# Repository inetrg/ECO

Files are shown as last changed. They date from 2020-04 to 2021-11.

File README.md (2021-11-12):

# Source Files for the ECO Sensor Box
The ECO sensor box is a versatile modular wireless sensor box for perpetual operation based on energy harvesting.
Using a self-adaptive power management the sensor self-adapts its power consumption according to energy availability,
based on real-time, online self measurement of its power consumption and availability.

This repository contains source and design files required to build your own ECO-enabled sensor box.
The initial version of the ECO box used separate independent modules which you can find in corresponding subfolders.
The newer version uses a more integrated approach by placing most of the subsystems onto a single PCB for easier setup.

## ECO Box Design Files
Below we list some notes on what to consider when working with the ECO Box design files.

## Tools and Files
All design files are being processed only using open source tools to make them accessible and reusable for everyone.

KiCAD is used for schematics and Layout of the custom PCB.
FreeCAD is used for mechanical design of the physical box assembly, including the enclosure, PCB, external sensors, antenna, etc.
Blender is used for further visualization/rendering purposes (custom materials, lighting etc.) for more sophisticated controls of visuals.

To exchange data between all these tools different formats are used and some of them need workarounds to make everything work as expected.

### FreeCAD -> KiCAD
As mentioned, FreeCAD is used for the mechanical part. So an easy way to get a fitting PCB outline for a given enclosure is to export the outline from there to KiCAD.
For this the DXF 2D export of FreeCAD is used and the exported drawing is then imported to the edge.cuts layer in KiCAD before doing the PCB layout.

For custom components that don't have a 3D-Symbol in KiCAD, we also use FreeCAD to desing them and use the STEP export to use them in KiCAD.

### KiCAD -> FreeCAD
With the PCB being done the whole PCB including associated 3D models for components can be imported from the *.kicad_pcb file using the KiCADStepUp Workbench of FreeCAD.
For this the "Load KiCAD PCB and Board Parts" was used.
A special case that required a workaround here was the "Add Tracks" feature that didn't work well and made FreeCAD crash frequently.
Instead the Tracks were exported to DXF from KiCAD and then imported using the "Add Silks" feature (custom colors can still be appied later on).

In FreeCAD any missing mechanical design can then be aligned around the PCB and its components.

### FreeCAD -> Blender
To export the whole model from FreeCAD to blender the format that worked best for us is *gltf.
However, there is a problem with colors/materials that are only applied to faces (instead of whole objects) and if exported directly to gltf the colors will disappear.
A workaround for that is to first export to "STEP with colors" then import to FreeCAD again, an then do the export to gltf for blender. This way the colors that are present on KiCAD models don't get lost.

# Third Party Material
Some CAD models of PCB components and the assembly design use third party material from [SnapEDA](https://www.snapeda.com/) and [GrabCAD](https://grabcad.com).

# Further Information
Firmware sources can be found in a [separate repository](https://github.com/inetrg/ECO-fw).
For more information also visit our [project website](https://eco.riot-apps.net).

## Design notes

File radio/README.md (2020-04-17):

# Adapter PCB to connect a [rpi802154-r1](http://openlabs.co/OSHW/Raspberry-Pi-802.15.4-radio) or [MRF24J40MA](http://www.microchip.com/wwwproducts/en/MRF24J40MA) module to nucleo / arduino boards

This simple shield can be used to connect the aforementioned radio modules to STM32 based boards like the [Nucleo-64 family](http://www.st.com/resource/en/user_manual/dm00105823.pdf) or various other boards that come with the well known arduino header.

The main reason for creating this shield is that I need a switch to disconnect the modules from their power supply in order to get rid of small leakage currents that occur even in sleep mode. This is done using a low side n-channel mosfet. Another point is that I need to do this for a few devices and I want them to have a more sturdy connection than the usual (error prone) breadboard and jumper wire tinkerng. Think: plug&play instead of fiddling with loose wires and always looking up pin configurations again.

While tossing together a custom shield, why not add some little features that can be used for demo applications? For this there are two LEDs (D_PWR_1 and D_ACT1) connected to the radio's supply voltage and the CS pin to display if the device is powered and active. This allows to easily visualize duty-cycling applications.
Keeping in mind the initial purpose (low-power) the LEDs can be disconnected using the jumpers JP1 and JP2.

As a quick reference this is how the pins are connected:

| rpi802154-r1 | MRF24J40MA | Nucleo Pin (name / connector) | Arduino Pin Name  |
|---|---|---|---|
| +3.3V (2) | Vin (10) | +3V3 / CN6[4] | +3V3 |
| GND (6,10) | GND (1,11,12) | *GND  / CN6[6,7], CN5[7]** | GND |
| MISO (4) | SDO (7) | PA6  / CN5[5] | D12 |
| MOSI (3) | SDI (5) | PA7  / CN5[4] | D11 |
| AT86_SEL (8) | CS  (8) | PB6  / CN5[3] | D10 |
| AT96_IRQ (12) | INT (4) | PA8  / CN9[8] | D7 |
| AT96_SLP_TR (9) | WAKE (3) | PB10 / CN9[7] | D6 |
| AT96_RST (11) | RESET (2) | PB4  / CN9[6] | D5 |
| SCK (5) | SCK (6) | PA5  / CN5[6] | D13 |

\* The GND of the radios are actually connected to the drain pad of the FET which in turn has its source pad connected to GND of the board.

| Additional function | Nucleo Pin (name / connector) | Arduino Pin Name  |
|---|---|---|
| FET drain (SOT-23 pad 1) | PA4  / CN8[3] | A2 |

---
## BOM

Below is the bill of materials for equipping the pcb. Obviously you can choose to use other parts as long as they have the same footprint and properties. For the lazy ones: you may want to look at [this pre-filled shopping cart at Mouser](https://www.mouser.com/ProjectManager/ProjectDetail.aspx?AccessID=bb2e666ecb) which contains all the parts needed to equip a single PCB.

| Component identifier | Part | cnt. | Mouser Link |
|---|---|---|---|
| J1, J2 | 1x6 Pin Header 2.54mm pitch female | 2 | [PMV20XNEA](https://www.mouser.com/ds/2/302/PMV20XNEA-1151838.pdf) |
| J3, J5 | 1x8 Pin Header 2.54mm pitch male | 2 | [855-M20-7820646](https://www.mouser.de/ProductDetail/855-M20-7820646) |
| J4 | 1x10 Pin Header 2.54mm pitch male  | 1 | [538-22-28-4102](https://www.mouser.de/ProductDetail/538-22-28-4102) |
| J6 | 1x6 Pin Header 2.54mm pitch male | 1 | [538-22-28-4062](https://www.mouser.de/ProductDetail/538-22-28-4062) |
| J7 | 2x6 Pin Header 2.54mm pitch male | 2 | [571-103777-3](https://www.mouser.de/ProductDetail/571-103777-3) |
| JP1, JP2 | 1x2 Pin Header 2.54mm pitch male | 2 | [571-826936-2](https://www.mouser.de/ProductDetail/571-826936-2) |
| - | Jumpers for JP1 and JP2 | 2 | [571-826936-2](https://www.mouser.de/ProductDetail/571-826936-2) |
| Q1 | SOT-23 n-channel MOSFET | 1 | [151-8010-E](https://www.mouser.de/ProductDetail/151-8010-E) |
| R1, R2 | 1.5k 0805 SMD resistor | 2 | [652-CR0805FX-1501ELF](https://www.mouser.de/ProductDetail/652-CR0805FX-1501ELF) |
| R3 | 8.2k 0805 SMD resistor | 1 | [652-CR0805JW-822ELF](https://www.mouser.de/ProductDetail/652-CR0805JW-822ELF) |
| R4, R5 (only one needed)  | 47k 0805 SMD resistor | 1 | [71-CRCW0805-47K-E3](https://www.mouser.de/ProductDetail/71-CRCW0805-47K-E3) |
| D_PWR_1, D_PWR_1 | 0805 SMD LED | 2 | [604-AP2012EC](https://www.mouser.de/ProductDetail/604-AP2012EC) |

---
## Configuration

To define your prefered default state of the supply switch you can either fit a pull-up resistor to R5 or a pull-down to R4. While this is true for the FET listed in the BOM above, using another FET might reverse the logic and/or need other resistor values to work properly.

| Setting | Configuration |
|---|---|
| Radio powered by default  | R4=not fitted / R5=47k |
| Radio disabled by default | R4=47k / R5=not fitted |
| LED D_PWR_1 disabled | JP1=open |
| LED D_ACT1 disabled | JP2=open |

---
### Using this shield with [RIOT](https://github.com/RIOT-OS/RIOT)
Depending on which module you want to use, copy one of the the following blocks to your applications Makefile.

**Note:**  Currently RIOT (more specifically it's radio driver(s)) doesn't handle power enable pins for the radios. This implies that you need to take care of enabling/disabling (and by that also initializing) the radio *manually*, wehen the R4/R5 pull resistors are configured to disable the supply by default.
Using RIOT's auto-init feature together with "radio disabled by default" configuration will not work out of the box unless you add the needed power-on functionality to the beginning of the drivers init-function. As an alternative you can also just disable auto_init.

```
USEMODULE += mrf24j40
CFLAGS += -DMRF24J40_PARAM_SPI=SPI_DEV\(0\)
CFLAGS += -DMRF24J40_PARAM_SPI_CLK=SPI_CLK_5MHZ
CFLAGS += -DMRF24J40_PARAM_CS=GPIO_PIN\(1,6\)
CFLAGS += -DMRF24J40_PARAM_INT=GPIO_PIN\(0,8\)
CFLAGS += -DMRF24J40_PARAM_RESET=GPIO_PIN\(1,4\)

CFLAGS += -DRADIO_SUPPLY_SWITCH_PINT=GPIO_PIN\(0,4\)
```

```
USEMODULE += at86rf2xx
CFLAGS += -DAT86RF2XX_PARAM_SPI=SPI_DEV\(0\)
CFLAGS += -DAT86RF2XX_PARAM_SPI_CLK=SPI_CLK_5MHZ
CFLAGS += -DAT86RF2XX_PARAM_CS=GPIO_PIN\(1,6\)
CFLAGS += -DAT86RF2XX_PARAM_INT=GPIO_PIN\(0,8\)
CFLAGS += -DAT86RF2XX_PARAM_SLEEP=GPIO_PIN\(1,10\)
CFLAGS += -DAT86RF2XX_PARAM_RESET=GPIO_PIN\(1,4\)

CFLAGS += -DRADIO_SUPPLY_SWITCH_PINT=GPIO_PIN\(0,4\)
```

---

(c) by Michel Rottleuthner
The files in this folder are licensed under a Creative Commons Attribution 4.0 International License.
You should have received a copy of the license along with this work. If not, see .

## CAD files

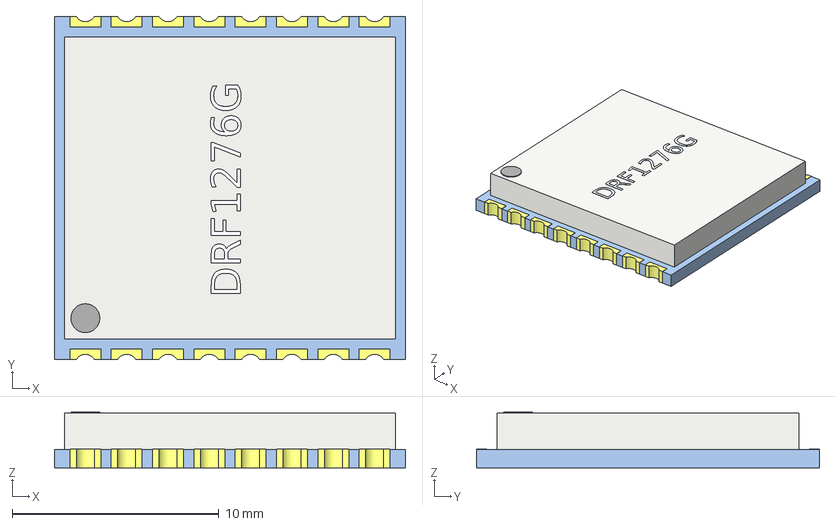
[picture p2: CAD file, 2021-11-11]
CAD/DRF1276G/DRF1276G-Part.step
17.0 x 16.6 x 2.70 mm
house
marker

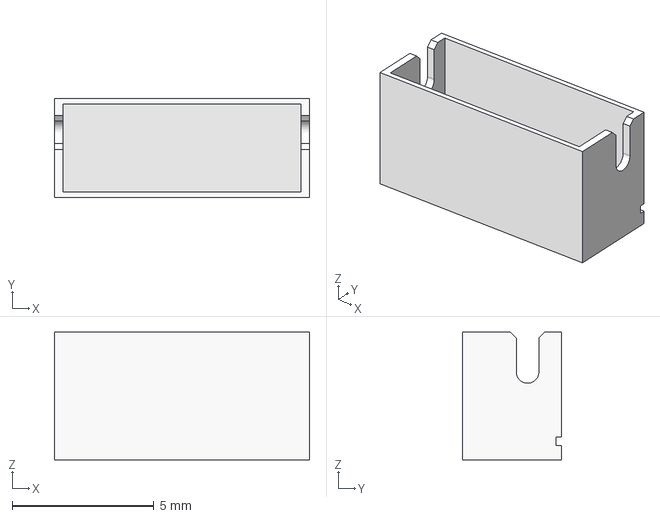
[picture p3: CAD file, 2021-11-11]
CAD/JST_B5B_ZR/jst_b5b_connector.FCStd
9.00 x 3.50 x 4.50 mm

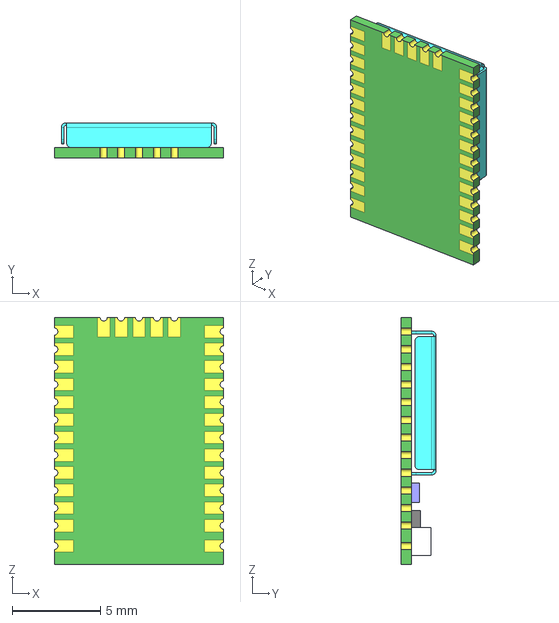
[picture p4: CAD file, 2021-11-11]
CAD/Quectel_L96_GNSS/L96--3DModel-STEP-46669.STEP
9.60 x 2.00 x 14.0 mm
L96-PCB
L96-COVER

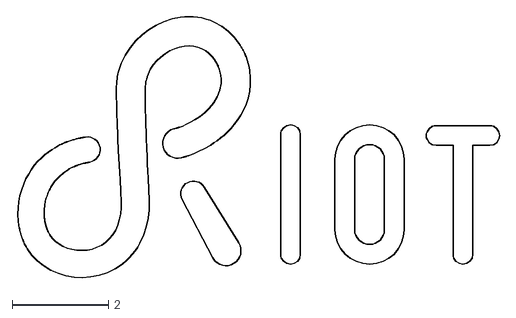
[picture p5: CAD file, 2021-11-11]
logos/RIOT.dxf
10.1 x 5.44

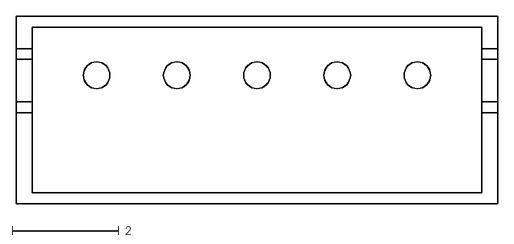
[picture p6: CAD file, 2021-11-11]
CAD/JST_B5B_ZR/jst_b5b_connector-Shape2DView.dxf
9.00 x 3.50

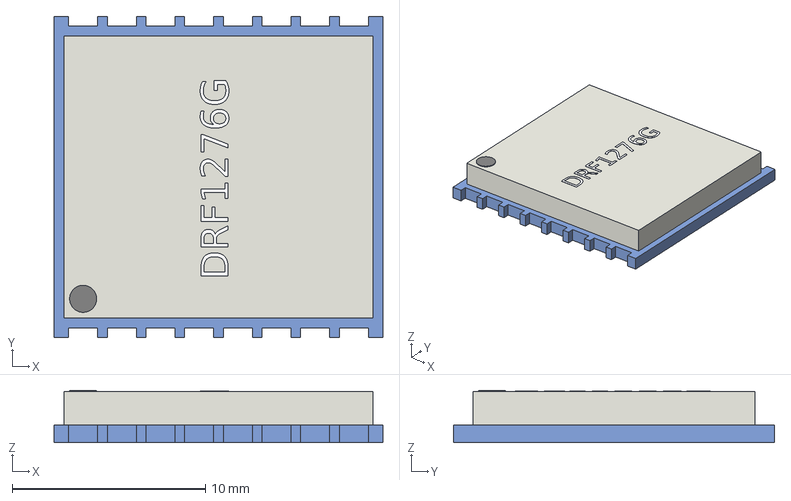
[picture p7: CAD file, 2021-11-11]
CAD/DRF1276G.FCStd
17.0 x 16.6 x 2.70 mm
house
marker

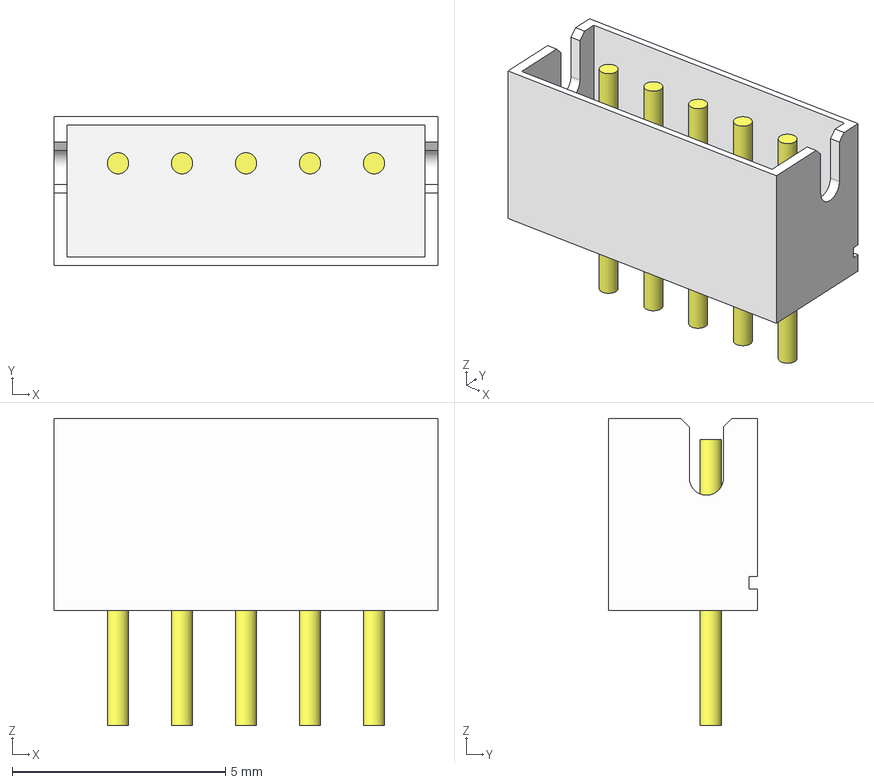
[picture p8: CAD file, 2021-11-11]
CAD/JST_B5B_ZR/jst_b5b_connector-Part.step
9.00 x 3.50 x 7.20 mm

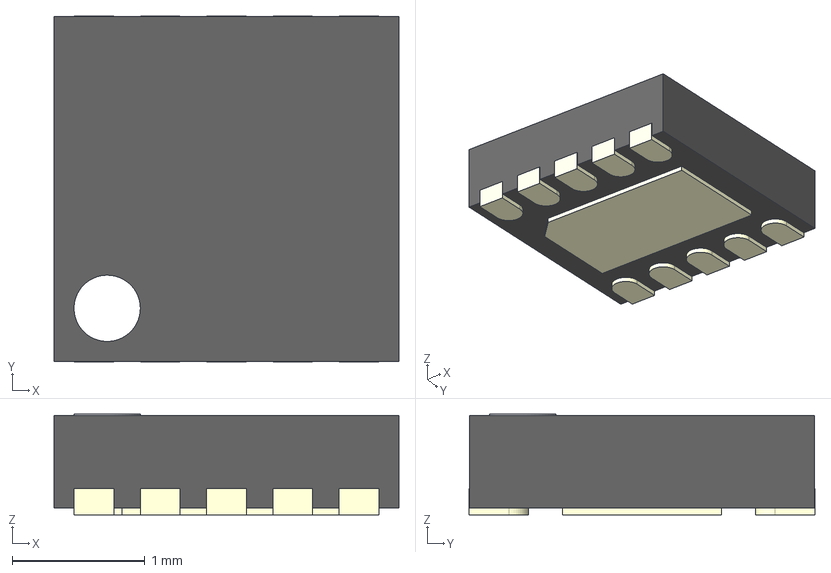
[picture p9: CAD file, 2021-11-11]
CAD/TPS63900-TPS63900_WSON.step
2.60 x 2.61 x 0.76 mm

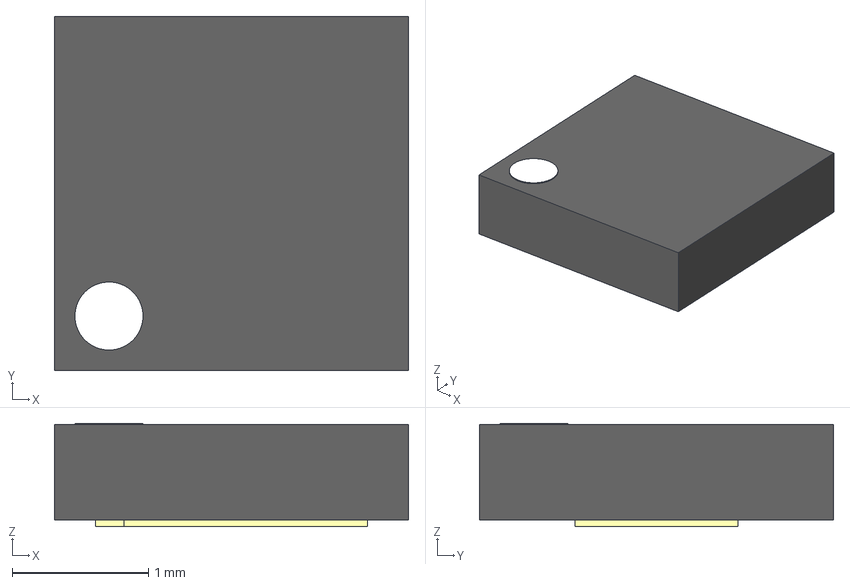
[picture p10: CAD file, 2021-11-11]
CAD/TPS63900.FCStd
2.60 x 2.60 x 0.76 mm

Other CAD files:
CAD/TPS63900-TPS63900_WSON.stl

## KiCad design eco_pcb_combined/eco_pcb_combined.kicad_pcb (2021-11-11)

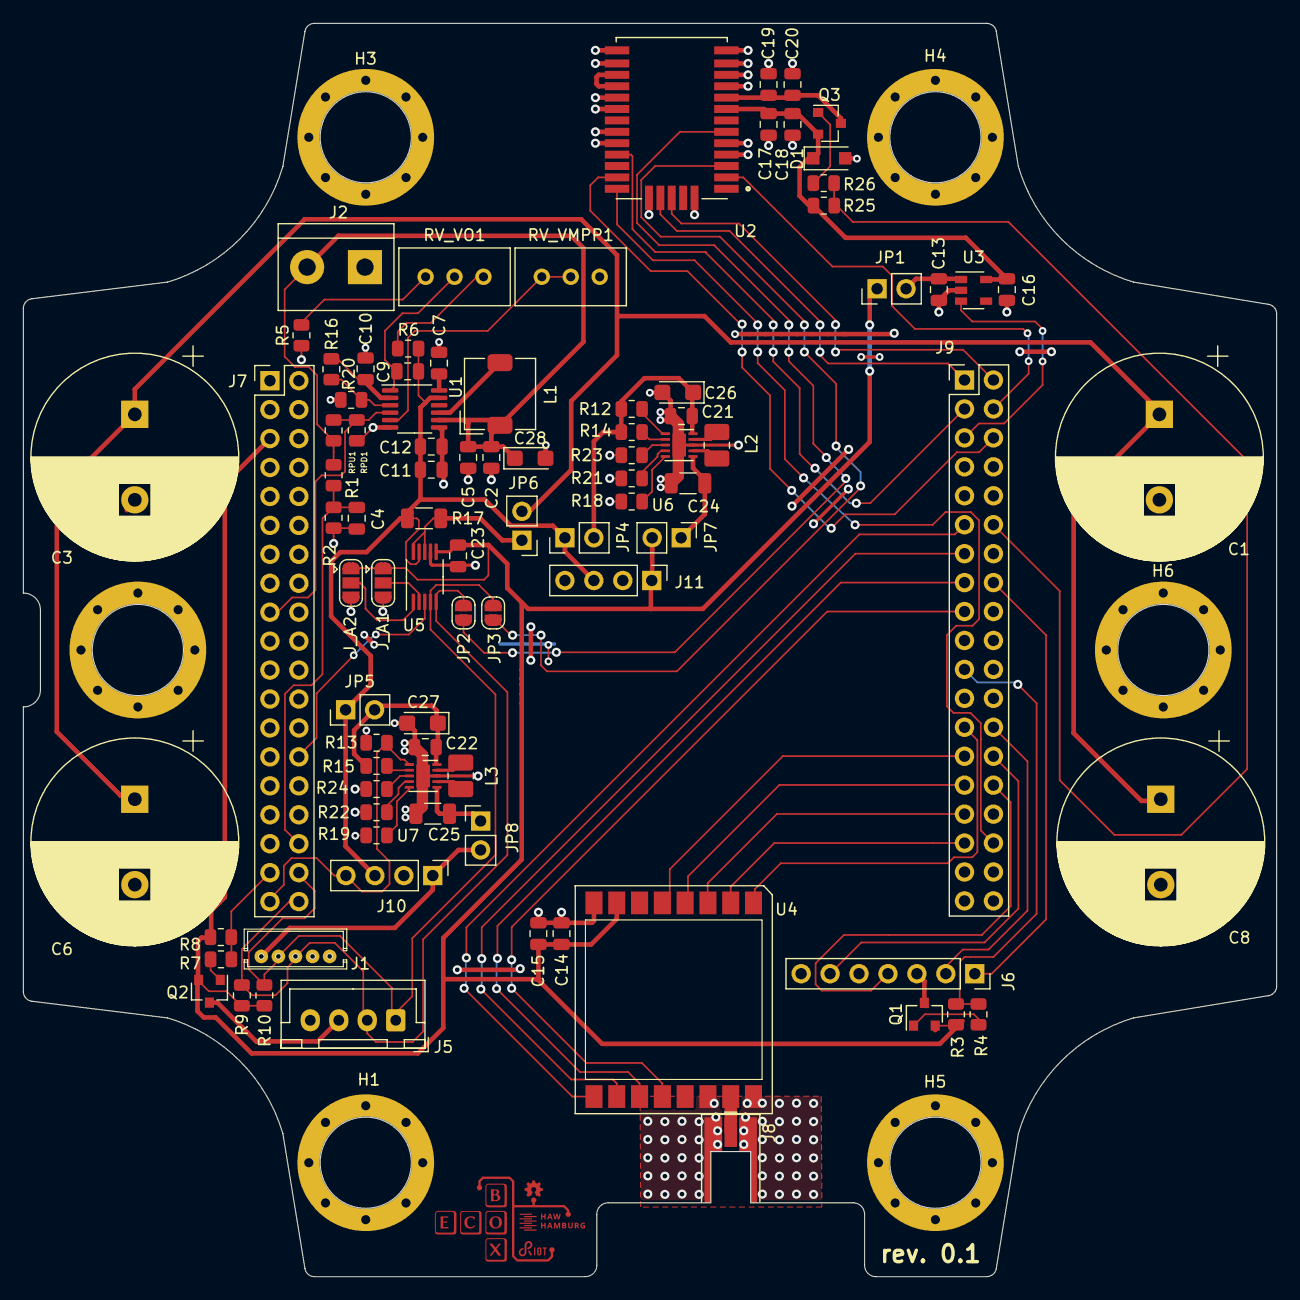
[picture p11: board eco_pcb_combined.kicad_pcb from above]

Board: 2 copper layers, 110.0 x 110.0 mm, 97 parts (1 on the bottom side), 75 nets.

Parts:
C1, C3, C6, C8: 50F-100F; CP_Radial_D18.0mm_P7.50mm
C2, C11, C14, C20, C21, C22: 10µF; C_0805_2012Metric
C4: 1nF; C_0805_2012Metric
C5, C7, C12, C13, C16: 1µF; C_0805_2012Metric
C9: 22pF; C_0805_2012Metric
C10, C18: 4.7µF; C_0805_2012Metric
C15, C17, C19, C23: 100nF; C_0805_2012Metric
C24, C25: 22µF; C_1206_3216Metric
C26, C27, C28: 47µF; CP_EIA-3216-10_Kemet-I
D1: Littlefuse_TVS_SMF3.3; D_SOD-123F
H1, H2, H3, H4, H5, H6: MountingHole; MountingHole_8.1mm_M8_Pad_Via
J1: Conn_01x05; JST_B5B_ZR
J2: Screw_Terminal_01x02; TerminalBlock_bornier-2_P5.08mm
J5: Conn_01x04; JST_XH_B4B-XH-A_1x04_P2.50mm_Vertical
J6: BOB-00544; PinSocket_1x07_P2.54mm_Vertical
J7, J9: Conn_02x19_Odd_Even; PinHeader_2x19_P2.54mm_Vertical
J8: Conn_Coaxial; MMCX_Molex_73415-0961_Horizontal_1.6mm-PCB
J10, J11: Conn_01x04_Female; PinHeader_1x04_P2.54mm_Vertical
JP1, JP4, JP5, JP6, JP7, JP8: Jumper_2_Bridged; PinHeader_1x02_P2.54mm_Vertical
JP2, JP3: Jumper_NC_Small; SolderJumper-2_P1.3mm_Open_RoundedPad1.0x1.5mm
J_A1, J_A2: JP2E; SolderJumper-3_P1.3mm_Open_RoundedPad1.0x1.5mm
L1: 10µH; L_TDK_SLF6045
L2, L3: 2.2µH; L_1008_2520Metric_Pad1.43x2.20mm_HandSolder
LOGO1: Logo; RIOT_ECO_HAW_OSHW_straight
Q1, Q2, Q3: Si2329DS; SOT-23
R1, R16: 1MΩ; R_0805_2012Metric
R2, R5: 390kΩ; R_0805_2012Metric
R3, R8, R12, R13, R14, R15, R26: 100kΩ; R_0805_2012Metric
R4, R7, R25: 330Ω; R_0805_2012Metric
R6: 1.1MΩ; R_0805_2012Metric
R9, R10: 4.7kΩ; R_0805_2012Metric
R17: 0.27Ω; R_1206_3216Metric
R18, R19, R21, R22: 0Ω; R_0805_2012Metric
R20: 2.5MΩ; R_0805_2012Metric
R23, R24: 36.5kΩ; R_0805_2012Metric
RPD1: 100kΩ; R_0805_2012Metric
RPU1: 100kΩ; R_0805_2012Metric
RV_VMPP1: 500kΩ; Potentiometer_Bourns_3296W_Vertical
RV_VO1: 500kΩ; Potentiometer_Bourns_3296W_Vertical
U1: LTC3105; MSOP-12_3x4mm_P0.65mm
U2: L96; XCVR_L96
U3: TPS7A0230PDBVR; SOT-23-5
U4: DORJI_DRF1276G; DRF1276G
U5: INA226INA226AIDGS; VSSOP-10_3x3mm_P0.5mm
U6, U7: TPS63900; WSON-10-1EP_2.5x2.5mm_P0.5mm_EP1.2x2mm

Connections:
3V3: C14.2, C15.2, C23.2, J7.5, J11.1, JP1.1, JP7.2, J_A1.1, J_A2.1, Q1.2, Q2.2, R3.1, R8.1, R9.1, R10.1, U4.7, U5.6
3V3_EXT_I2C: J5.3, Q2.3
3V3_SDCARD: J6.3, Q1.3
3V_GPS: C16.2, C17.2, C18.2, D1.1, Q3.2, R26.1, U2.8, U3.5
5V: J1.5, J10.1, JP8.2
/IN+: JP6.1, R17.2, U5.8, U5.10
A0_PA0_WKUP1|INA_ALERT: J7.28, U5.3
A3_PB0|PV_OCV_SENSE: C4.2, J7.34, R1.1, R2.2
D2_PA10|LORA_DIO0: J9.33, U4.2
D3_PB3|LORA_DIO1: J9.31, U4.3
D4_PB5|LORA_DIO2: J9.29, U4.4
D5_PB4|LORA_DIO3: J9.27, U4.5
D6_PB10|LORA_RESET: J9.25, U4.1
D8_PA9|SDCARD_PWR_SW: J9.21, R3.2, R4.1
D10_PB6|LORA_CS: J9.17, U4.12
D11_PA7|LORA_MOSI: J9.15, U4.11
D12_PA6|LORA_MISO: J9.13, U4.10
D13_PA5|LORA_SCK_LED2: J9.11, U4.9
FBLDO: R16.1, R20.2, U1.3
GND: C1.2, C2.2, C3.2, C4.1, C5.2, C6.2, C7.1, C8.2, C10.1, C11.1, C12.1, C13.1, C14.1, C15.1, C16.1, C17.1, C18.1, C19.1, C20.1, C21.1, C22.1, C23.1, C24.1, C25.1, C26.2, C27.2, C28.2, D1.2, J1.1, J1.2, J2.1, J5.4, J6.5, J7.8, J7.19, J7.20, J7.22, J8.2, J9.9, J9.20, J10.2, J11.2, J_A1.3, J_A2.3, R2.1, R5.1, R13.2, R18.1, R19.1, R20.1, R21.1, R22.1, R23.1, R24.1, RPD1.2, RV_VMPP1.1, U1.6, U1.7, U2.4, U2.5, U2.10, U2.11, U2.12, U2.13, U2.14, U2.15, U2.18, U2.19, U2.21, U2.22, U2.27, U2.31, U3.2, U4.8, U4.14, U4.16, U5.7, U6.8, U6.11, U7.8, U7.11
LDO: C10.2, R16.2, U1.2
LORA_ANT: J8.1, U4.15
unnamed: C7.2, U1.12
unnamed: C9.1, RV_VO1.2, U1.1
unnamed: C13.2, JP1.2, U3.1
unnamed: C19.2, C20.2, Q3.3, U2.9
unnamed: C21.2, C26.1, JP4.2, R12.2, R14.2, U6.10
unnamed: C22.2, C27.1, JP5.2, R15.2, U7.10
unnamed: C24.2, JP7.1, U6.6
unnamed: C25.2, JP8.1, U7.6
unnamed: JP2.2, U2.6
unnamed: JP3.2, U2.3
unnamed: J_A1.2, U5.2
unnamed: J_A2.2, U5.1
unnamed: L1.2, U1.9
unnamed: L2.1, U6.7
unnamed: L2.2, U6.9
unnamed: L3.1, U7.7
unnamed: L3.2, U7.9
unnamed: Q1.1, R4.2
unnamed: Q2.1, R7.2
unnamed: Q3.1, R25.2
unnamed: R5.2, RV_VO1.3
unnamed: R6.2, RV_VO1.1
unnamed: R12.1, U6.1
unnamed: R14.1, U6.2
unnamed: R15.1, U7.2
unnamed: R18.2, U6.5
unnamed: R19.2, U7.5
unnamed: R21.2, U6.4
unnamed: R22.2, U7.4
unnamed: R23.2, U6.3
unnamed: R24.2, U7.3
unnamed: RV_VMPP1.2, RV_VMPP1.3, U1.5
unnamed: U2.16, U2.17
PA12: J9.12, R25.1, R26.2
PA15|LTC_SHDN: J7.17, RPD1.1, RPU1.1, U1.4
PB8_D15|GPS_NRESET: J9.3, U2.23
PB9_D14|GPS_SUP_EN: J9.5, U3.3
PB12|SDCARD_CS: J6.1, J9.16
PB13|SDCARD_SCK: J6.4, J9.30
PB14|SDCARD_MISO: J6.6, J9.28
PB15|SDCARD_MOSI: J6.2, J9.26
PC0|I2C_SCL: J1.3, J5.2, J7.38, JP2.1, R9.2, U5.5
PC1|I2C_SDA: J1.4, J5.1, J7.36, JP3.1, R10.2, U5.4
PC2|EXT_SENS_3V3_SW: J7.35, R7.1, R8.2
PC3|5V_EN: J7.37, J10.4, R13.1, U7.1
PC4|GPS_UART_RX_U1TX: J9.34, U2.26
PC5|GPS_UART_TX_U1RX_WKUP5: J9.6, U2.25
PC6|GPS_3D_FIX: J9.4, U2.2
PC8|GPS_TIME_PULSE: J9.2, U2.29
PC9|GPS_FORCE_ON: J9.1, U2.28
PV+: C2.1, C5.1, C28.1, J2.2, L1.1, R1.2, RPU1.2, U1.8
VSC: C1.1, C3.1, C6.1, C8.1, JP6.2
V_CHGREG: C9.2, C11.2, C12.2, J10.3, J11.3, JP4.1, JP5.1, R6.1, R17.1, U1.11, U5.9

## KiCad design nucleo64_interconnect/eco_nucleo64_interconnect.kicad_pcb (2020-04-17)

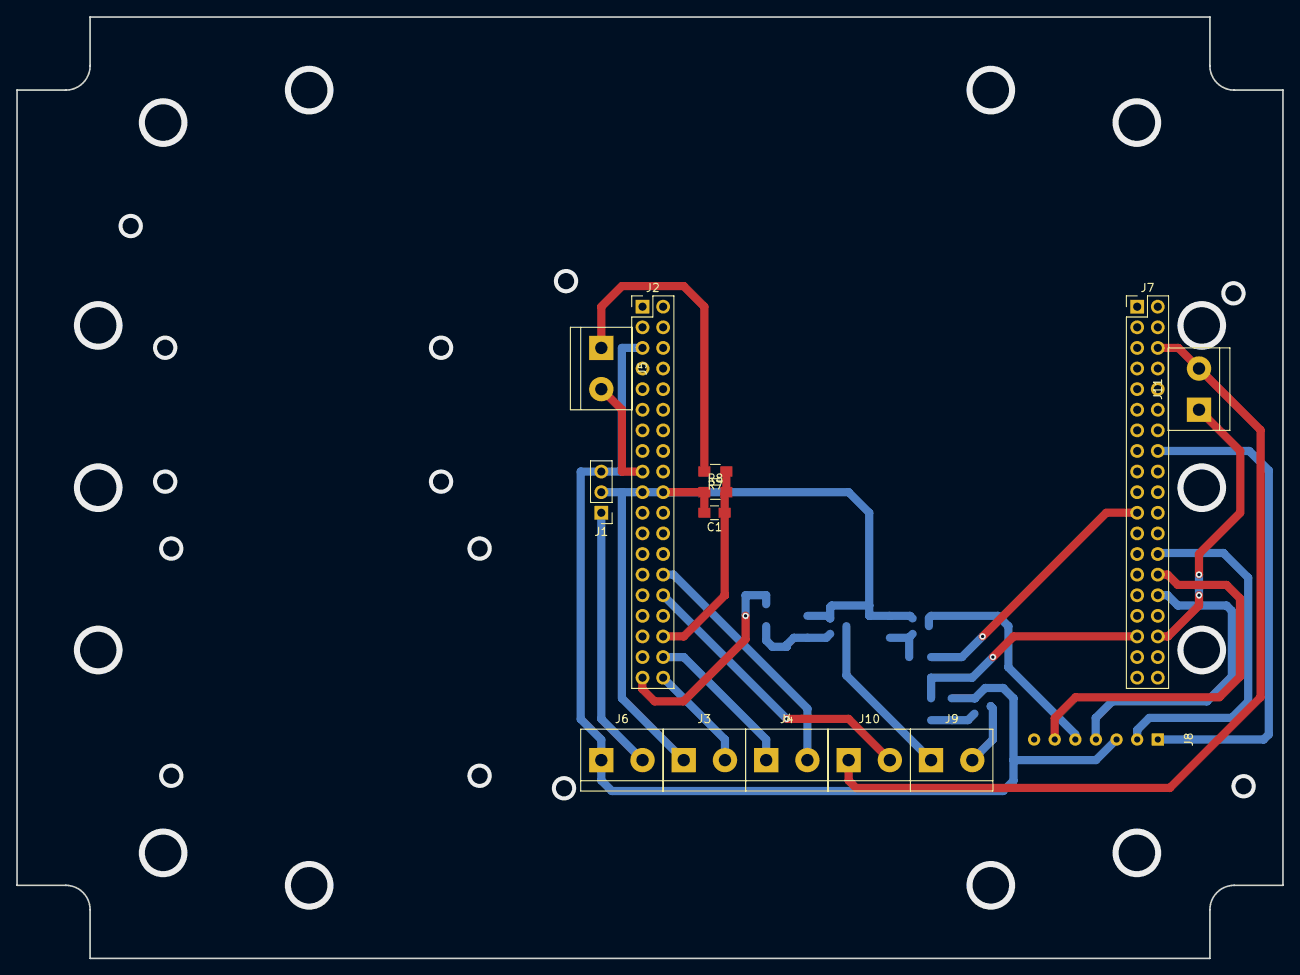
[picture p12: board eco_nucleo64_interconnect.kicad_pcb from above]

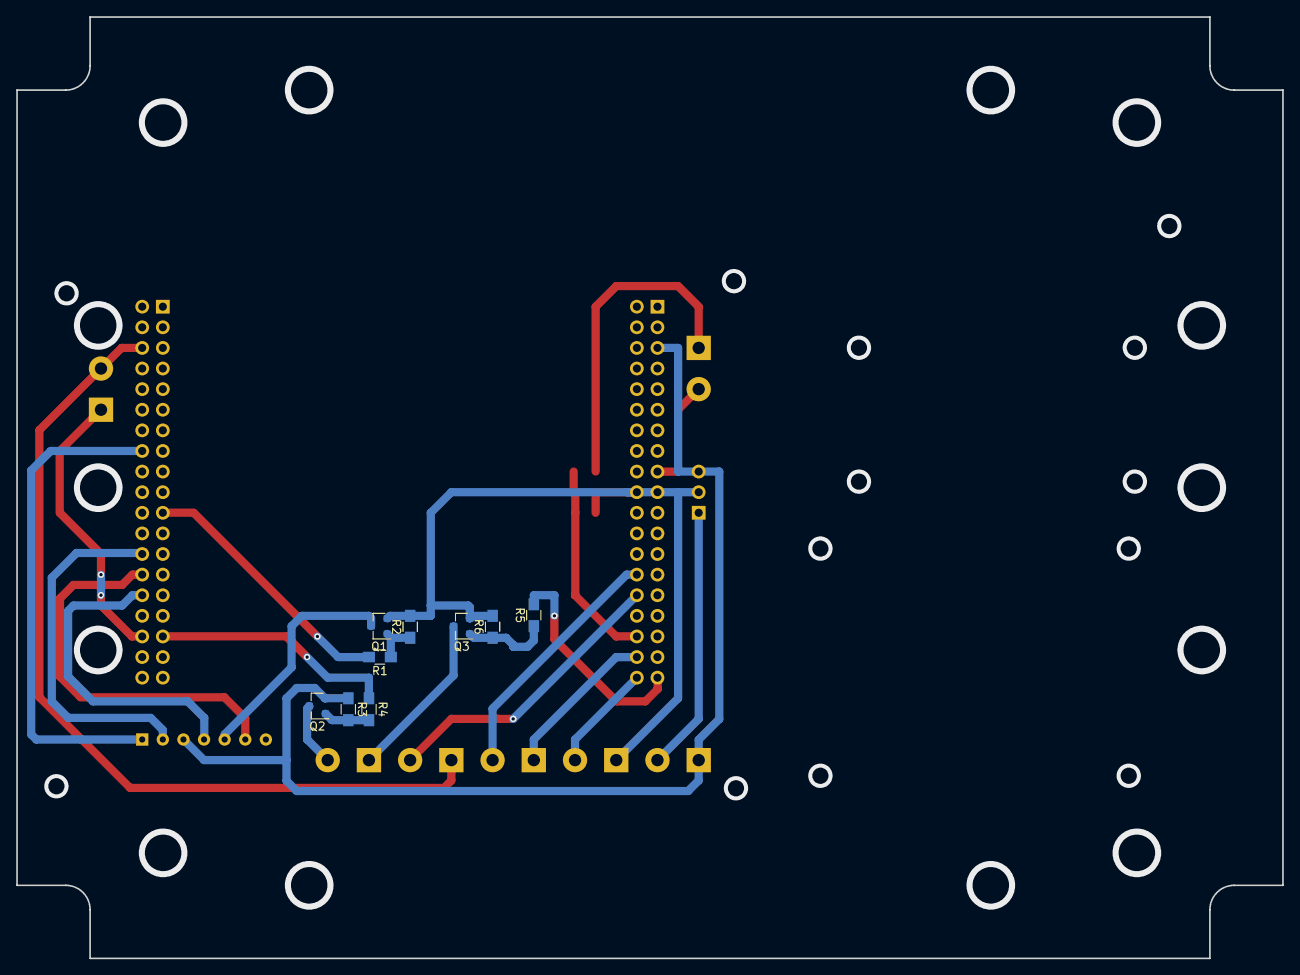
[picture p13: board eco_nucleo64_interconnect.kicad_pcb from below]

Board: 2 copper layers, 156.0 x 116.0 mm, 23 parts (9 on the bottom side), 25 nets.

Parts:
C1: 1n; C_0805_HandSoldering
J1: Conn_01x03; Pin_Header_Straight_1x03_Pitch2.54mm
J2, J7: Conn_02x19_Odd_Even; Pin_Header_Straight_2x19_Pitch2.54mm
J3, J4, J5, J6, J9, J10, J11: Screw_Terminal_01x02; TerminalBlock_bornier-2_P5.08mm
J8: BOB-00544
Q1, Q3: BSS138; SOT-23
Q2: NTR2101P; SOT-23
R1, R2, R3, R4, R5, R6: R; R_0805_HandSoldering
R7: 1M; R_0805_HandSoldering
R8: 390k; R_0805_HandSoldering

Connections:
3V3: J1.3, J2.5, J6.1, J8.3, Q2.2, R3.1
3V3_SWITCHED: J9.2, Q2.3
A0_PA0_WKUP1: J2.28, J4.2
A1_PA1|GPAD: J2.30, J10.2
A3_PB0|PV_SENSE: C1.1, J2.34, R7.1, R8.2
CS_PB12|SD-CS: J7.16, J8.1
D2_PA10|GP-3V3-SW: J7.33, R4.1
D8_PA9|SD-PWR-SW: J7.21, R1.2
GND: C1.2, J1.2, J2.19, J2.20, J3.1, Q1.2, Q3.2, R2.2, R6.2, R8.1
GND_SWITCHED: J9.1, Q3.3
MISO_PB14|SD-DO: J7.28, J8.6
MOSI_PB15|SD-DI: J7.26, J8.2
unnamed: J8.5, Q1.3
unnamed: Q1.1, R1.1, R2.1
unnamed: Q2.1, R3.2, R4.2
unnamed: Q3.1, R5.1, R6.1
PA15|LTC_SHDN: J2.17, J5.2
PC0_SCL: J2.38, J3.2
PC1_SDA: J2.36, J4.1
PC3|GP-GND-SW: J2.37, R5.2
PC4_U1TX: J7.34, J11.1
PC5_U1RX_WKUP5|GPD: J7.6, J10.1, J11.2
PV+: J5.1, R7.2
SCK_PB13|SD-SCK: J7.30, J8.4
VIN: J1.1, J6.2

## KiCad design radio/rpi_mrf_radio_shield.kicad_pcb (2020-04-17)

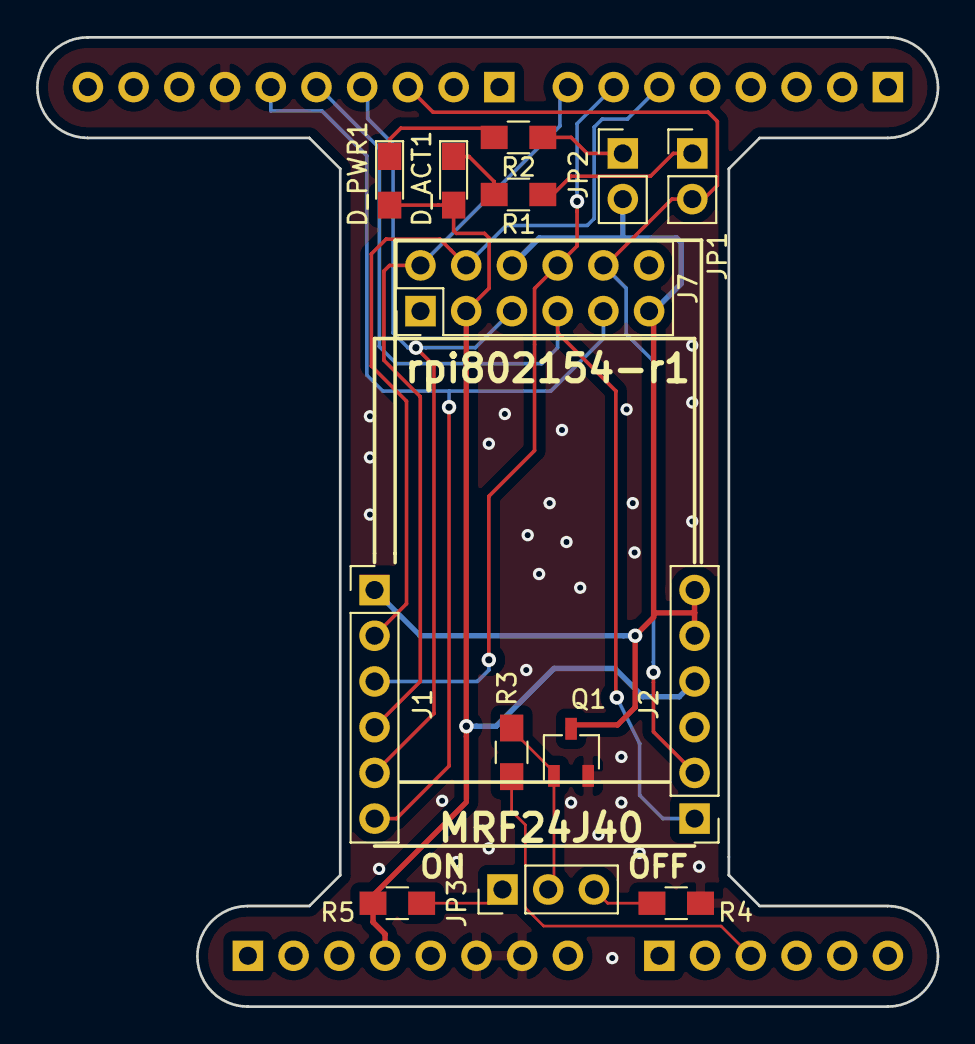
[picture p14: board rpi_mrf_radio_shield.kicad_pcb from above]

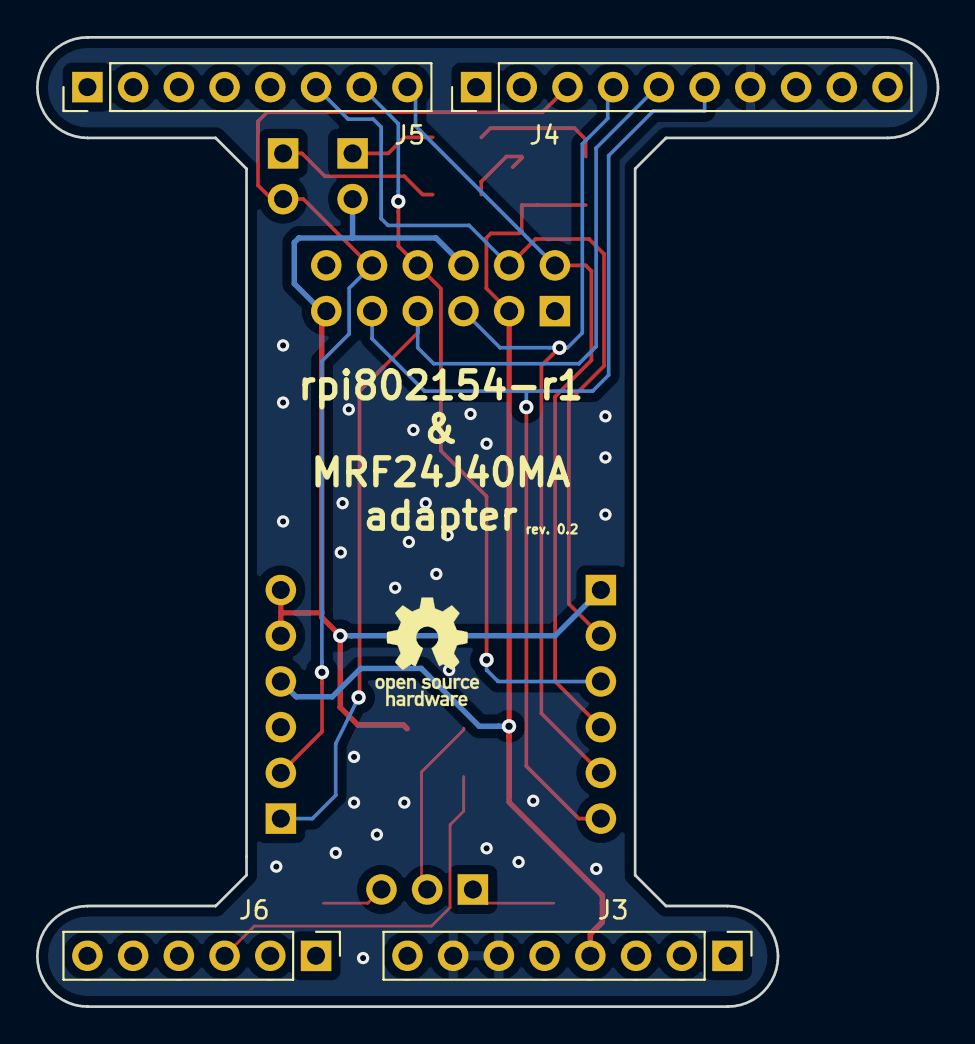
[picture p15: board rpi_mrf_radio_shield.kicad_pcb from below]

Board: 2 copper layers, 50.0 x 53.8 mm, 19 parts (5 on the bottom side), 18 nets.

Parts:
D_ACT1: LED; LED_0805_HandSoldering
D_PWR1: LED; LED_0805_HandSoldering
J1, J2: Conn_01x06_Female; Pin_Header_Straight_1x06_Pitch2.54mm
J3, J5: Conn_01x08_Male; Pin_Header_Straight_1x08_Pitch2.54mm
J4: Conn_01x10_Male; Pin_Header_Straight_1x10_Pitch2.54mm
J6: Conn_01x06_Male; Pin_Header_Straight_1x06_Pitch2.54mm
J7: Conn_02x06_Odd_Even; Pin_Header_Straight_2x06_Pitch2.54mm
JP1, JP2: Jumper; Pin_Header_Straight_1x02_Pitch2.54mm
JP3: J_on_off; Pin_Header_Straight_1x03_Pitch2.54mm
LOGO1: Logo_Open_Hardware_Small; OSHW-Logo_5.7x6mm_SilkScreen
Q1: MMBF170; TSOT-23
R1, R2: 1.5k; R_0805_HandSoldering
R3: 8k; R_0805_HandSoldering
R4: 47k; R_0805_HandSoldering
R5: <inf>k; R_0805_HandSoldering

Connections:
CS: J2.2, J4.3, J7.10, JP1.2
FET_D: J1.1, J2.5, J2.6, J7.6, J7.11, JP2.2, Q1.3
GND: J3.6, J3.7, J4.7, Q1.2, R4.1
INT: J1.4, J5.8, J7.2
MCU_SW: J6.3, R3.1
MISO: J2.1, J4.5, J7.7
MOSI: J1.5, J4.4, J7.5
unnamed: D_ACT1.1, R1.2
unnamed: D_PWR1.1, R2.2
unnamed: JP1.1, R1.1
unnamed: JP2.1, R2.1
unnamed: JP3.1, R5.1
unnamed: JP3.2, Q1.1, R3.2
unnamed: JP3.3, R4.2
RST: J1.2, J5.6, J7.4
SCK: J1.6, J4.6, J7.9
VCC: D_ACT1.2, D_PWR1.2, J2.4, J3.4, J7.3, R5.2
WAKE: J1.3, J5.7, J7.8

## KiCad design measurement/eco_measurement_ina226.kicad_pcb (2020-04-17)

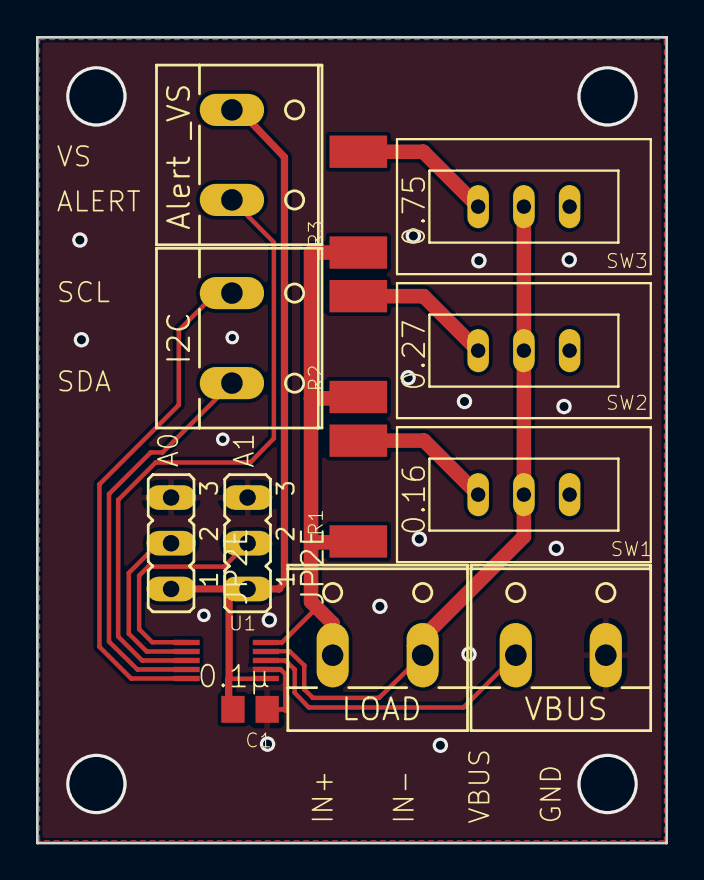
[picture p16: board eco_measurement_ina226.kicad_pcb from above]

Board: 2 copper layers, 35.0 x 44.8 mm, 14 parts (0 on the bottom side), 13 nets.

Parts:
C1: 0.1µ; C0805
J_A0, J_A1: JP2E; JP2
R1: 0.16; R2512
R2: 0.27; R2512
R3: 0.75; R2512
SW1, SW2, SW3: APEM_SWITCH_25000N25436NAH_3PIN; 25136NAH
U1: INA226INA226AIDGS; INA226_DGS_VSSOP_10
X1: LOAD; W237-102
X2: VBUS; W237-102
X4: Alert _VS; W237-102
X5: I2C; W237-102

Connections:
/IN+: R1.1, R2.1, R3.1, U1.10, X1.1
/IN-: SW1.P$2, SW2.P$2, SW3.P$2, U1.9, X1.2
/R1: R1.2, SW1.P$3
/R2: R2.2, SW2.P$3
/R3: R3.2, SW3.P$3
/VS: C1.2, J_A0.1, J_A1.1, U1.6, X4.1
GND: C1.1, J_A0.3, J_A1.3, U1.7, X2.2
unnamed: J_A0.2, U1.2
unnamed: J_A1.2, U1.1
unnamed: U1.3, X4.2
unnamed: U1.4, X5.2
unnamed: U1.5, X5.1
unnamed: U1.8, X2.1

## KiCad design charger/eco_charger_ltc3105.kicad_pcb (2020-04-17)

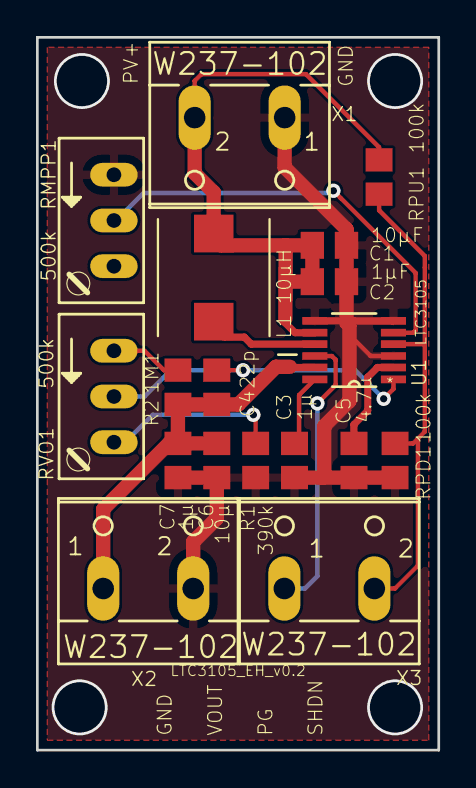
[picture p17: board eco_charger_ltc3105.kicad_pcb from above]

Board: 2 copper layers, 22.3 x 39.6 mm, 18 parts (0 on the bottom side), 12 nets.

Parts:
C1: 10µF; C0805
C2: 1µF; C0805
C3, C7: 1µ; C0805
C4: 22p; C0805
C5: 4.7µ; C0805
C6: 10µ; C0805
L1: 10µH; TDK_CLF_6045NI-D
R1: 390k; R0805
R2: 1M1; R0805
RMPP1: 500k; RJ9W
RPD1: 100k; R0805
RPU1: 100k; R0805
RVO1: 500k; RJ9W
U1: LTC3105; SOP65P490X110-12N
X1, X2, X3: W237-102

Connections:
/2.2V_LDO: C5.2, U1.2
/PGOOD: U1.10, X3.1
/PV+: C1.2, C2.2, L1.2, RPU1.2, U1.8, X1.2
/SHDN: RPD1.1, RPU1.1, U1.4, X3.2
/VOUT: C4.2, C6.2, C7.2, R2.1, U1.11, X2.1
GND: C1.1, C2.1, C3.1, C5.1, C6.1, C7.1, R1.1, RMPP1.E, RPD1.2, U1.3, U1.6, U1.7, X1.1, X2.2
unnamed: C3.2, U1.12
unnamed: C4.1, RVO1.S, U1.1
unnamed: L1.1, U1.9
unnamed: R1.2, RVO1.A
unnamed: R2.2, RVO1.E
unnamed: RMPP1.S, U1.5

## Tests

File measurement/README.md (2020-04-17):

# RIOT Energy-Harvesting Monitor using INA226

This module can be used to measure voltage and current of a connected load.
It comes with three different measurement ranges that can be freely configured by mounting different shunt resistors.
Depending on your use case you can switch between the measurement ranges with the slider switches.
The configuration of the board hosts jumpers to configure four different I2C slave addresses.

---
## BOM

Below is the bill of materials for equipping the pcb. Obviously you can choose to use other parts as long as they have the same footprint and properties. For the lazy ones: you may want to look at [this pre-filled shopping cart at Mouser](https://www.mouser.com/ProjectManager/ProjectDetail.aspx?AccessID=cd3d5edc18) which contains all the parts needed to equip a single PCB.

| Component identifier | Part | cnt. | Mouser Link |
|---|---|---|---|
| U1 | INA226 VSSOP-10 | 1 | [595-INA226AIDGSR](https://www.mouser.de/ProductDetail/595-INA226AIDGSR) |
| SW1, SW2, SW3 | Slide Switches SPDT 4A 125V | 3 | [642-25136NAH ](https://www.mouser.de/ProductDetail/642-25136NAH) |
| R1 | 0.1 Ohm 0.5% current sense resistor | 1 | [660-SLW1TTER100D](https://www.mouser.de/ProductDetail/660-SLW1TTER100D) |
| R2 | 1 Ohm 0.5% current sense resistor | 1 | [660-SL1TTE1R00D](https://www.mouser.de/ProductDetail/660-SL1TTE1R00D) |
| R3 | 2 Ohm 0.5% current sense resistor | 1 | [660-SL1TTE2R00D](https://www.mouser.de/ProductDetail/660-SL1TTE2R00D) |
| C1 | 0.1 µF Capacitor | 1 | [77-VJ0805Y104JXXAC](https://www.mouser.de/ProductDetail/77-VJ0805Y104JXXAC) |
| - | Jumper | 2 | [151-8010-E](https://www.mouser.de/ProductDetail/151-8010-E) |
| X1, X2, X3, X4 | Fixed Terminal screw clamp 2P | 4 | [504-EM366002](https://www.mouser.de/ProductDetail/504-EM366002) |
| JP1, JP1 | 1x3 Pin Header 2.54mm pitch male | 2 | [538-22-28-4031](https://www.mouser.de/ProductDetail/538-22-28-4031) |

---
## Configuration

With the jumpers on JP1 and JP2 you can configure the I2C slave address according to the following table.

| JPA1 | JPA0 | A1 Pin  | A0 Pin  | Address  |
|---|---|---|---|---|
|  1 2-3  |  1 2-3  |  GND |  GND |  0x40 |
|  1 2-3  |  1-2 3  |  GND |  VS |  0x41 |
|  1-2 3  |  1 2-3  |  VS |  GND |  0x44 |
|  1-2 3  |  1-2 3  |  VS |  VS |  0x45 |

---

(c) by Michel Rottleuthner
The files in this folder are licensed under a Creative Commons Attribution 4.0 International License.
You should have received a copy of the license along with this work. If not, see .

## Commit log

2020-04-17 add sources for charger module
    [eco_charger_ltc3105-B_Mask.gbs, eco_charger_ltc3105-B_Paste.gbp, eco_charger_ltc3105-B_SilkS.gbo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]
2020-04-17 add sources for measurement module
    [eco_measurement_ina226-B_Mask.gbs, eco_measurement_ina226-B_Paste.gbp, eco_measurement_ina226-B_SilkS.gbo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]
2020-04-17 add sources for radio module
    [rpi_mrf_radio_shield-B_Cu.gbl, rpi_mrf_radio_shield-B_Mask.gbs, rpi_mrf_radio_shield-B_SilkS.gbo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]
2020-04-17 add sources for interconnect module
    [eco_nucleo64_interconnect-B_Cu.gbl, eco_nucleo64_interconnect-B_Mask.gbs, eco_nucleo64_interconnect-B_Paste.gbp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]
2021-11-11 add pcb design files, libs, and logos of combined board for v2
    [RIOT.dxf, eco_pcb_combined.kicad_pcb, eco_pcb_combined.sch]
2021-11-11 add 3d CAD models for box assembly and custom parts
    [DRF1276G-Part.step, DRF1276G.FCStd, L96--3DModel-STEP-46669.STEP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]
2021-11-11 add blender file that combines KiCAD and FreeCAD models for more advanced postprocessing for visualization
2021-11-11 add Makefile for gerber archive and pinmap generation

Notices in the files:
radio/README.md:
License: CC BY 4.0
